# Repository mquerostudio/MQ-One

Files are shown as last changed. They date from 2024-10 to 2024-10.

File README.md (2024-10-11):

# MQ One

Este repositorio contiene todos los archivos creados para mi Trabajo Final de Grado y el **MQ One**: 

***Diseño, validación e implementación de un dispositivo electrónico programable modular***

El proyecto se ha centrado en el **diseño de una nueva plataforma educativa** que facilite el aprendizaje de la **programación de microcontroladores.**

<div align="center">
  
</div>

Para ello he desarrollado el **MQ One**, un dispositivo electrónico programable modular. Incluye **todos los componentes necesarios para enseñar de simple y divertida programación de sistemas embebidos.** Por ello incluye desde los componentes más simples como un encoder y LEDs, hasta más avanzados como una pantalla, una IMU, microSD, micrófono y altavoz.

Toda la información la puedes encontrar en mi web: **[mquero.com](https://mquero.com/)**

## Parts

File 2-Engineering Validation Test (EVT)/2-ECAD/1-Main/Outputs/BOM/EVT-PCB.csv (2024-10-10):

Reference | Value | MQ PN | Part Number | Footprint | Qty
C201,C304,C501,C531,C703,C705,C901,C1001,C1201 | 10u |  |  | Capacitor_SMD:C_0402_1005Metric | 9
C202,C305,C401,C502,C504,C505,C506,C507,C508,C509,C510,C511,C512,C513,C514,C515,C516,C517,C518,C519,C520,C521,C522,C523,C524,C525,C526,C527,C529,C530,C532,C601,C801,C802,C803,C902,C1002,C1103,C1104,C1106,C1108,C1109,C1202,C1205,C1206 | 100n |  |  | Capacitor_SMD:C_0402_1005Metric | 45
C203,C402,C503,C528,C1102,C1105,C1107,C1110,C1203 | 1u |  |  | Capacitor_SMD:C_0402_1005Metric | 9
C302 | 15p |  |  | Capacitor_SMD:C_0402_1005Metric | 1
C303 | 10u | TFGC001 | GRM188R60J106ME47D | Capacitor_SMD:C_0402_1005Metric | 1
C533,C534 | 10n |  |  | Capacitor_SMD:C_0402_1005Metric | 2
C804,C805,C1101 | 22p |  |  | Capacitor_SMD:C_0402_1005Metric | 3
C301,C403,C701 | 22u |  |  | Capacitor_SMD:C_0603_1608Metric | 3
J1302 | Conn_01x09 |  |  | Connector_PinSocket_2.54mm:PinSocket_1x09_P2.54mm_Vertical | 1
J1304 | Conn_01x15 |  |  | Connector_PinSocket_2.54mm:PinSocket_1x15_P2.54mm_Vertical | 1
D1201 | LED |  |  | LED_SMD:LED_0603_1608Metric | 1
R101,R102,R103,R104,R107 | 2k2 |  |  | Resistor_SMD:R_0402_1005Metric | 5
R105,R108,R201,R301,R402,R403,R404,R407,R503,R504,R505,R506,R507,R508,R801,R1101,R1102 | 10k |  |  | Resistor_SMD:R_0402_1005Metric | 17
R109,R110 | 22R |  |  | Resistor_SMD:R_0402_1005Metric | 2
R302,R303 | 5.1k |  |  | Resistor_SMD:R_0402_1005Metric | 2
R304 | 220k |  |  | Resistor_SMD:R_0402_1005Metric | 1
R305 | 48k7 |  |  | Resistor_SMD:R_0402_1005Metric | 1
R306,R601 | 100k |  |  | Resistor_SMD:R_0402_1005Metric | 2
R308,R1201 | 330 |  |  | Resistor_SMD:R_0402_1005Metric | 2
R309 | 1M |  |  | Resistor_SMD:R_0402_1005Metric | 1
R401 | 2k |  |  | Resistor_SMD:R_0402_1005Metric | 1
R405,R501 | 1k |  |  | Resistor_SMD:R_0402_1005Metric | 2
R406 | 150k |  |  | Resistor_SMD:R_0402_1005Metric | 1
R502 | 470 |  |  | Resistor_SMD:R_0402_1005Metric | 1
R901,R902,R903,R904,R905 | 47k |  |  | Resistor_SMD:R_0402_1005Metric | 5
R1001 | 620k |  |  | Resistor_SMD:R_0402_1005Metric | 1
R1103 | 0 |  |  | Resistor_SMD:R_0402_1005Metric | 1
TP101,TP102,TP103,TP104,TP105,TP106,TP107,TP108,TP109,TP110,TP111,TP112,TP113,TP114,TP115,TP116,TP117,TP118,TP119,TP120,TP121,TP122,TP123,TP201,TP202,TP301,TP401,TP501,TP502,TP503,TP504,TP505,TP506,TP507,TP508,TP1001,TP1002,TP1101,TP1102,TP1103,TP1104,TP1108,TP1202,TP1203,TP1204,TP1209,TP1210,TP1301,TP1302,TP1303 | TestPoint |  |  | TestPoint:TestPoint_Pad_D1.0mm | 50
J701 | 2-2328724-1 | TFGJ002 |  | TFG:2-2328724-1 | 1
X801 | 9HT10-32.768KBZF-T | TFGX001 |  | TFG:9HT1032768KEZFT | 1
X1101 | ASE-24.000MHZ-L-R-T | TFGX002 |  | TFG:ASE24576MHZLCT | 1
IC501 | ATSAMD21G18A-MUT | TFGIC015 |  | TFG:ATSAMD21G18A-MUT | 1
D302 | BAT54CWT1G | TFGD005 |  | TFG:BAT54CWT1G | 1
U1202 | BME280 | TFGIC010 |  | TFG:BME280 | 1
U801 | BNO085 | TFGIC004 |  | TFG:BNO085 | 1
Q101 | BSS138-7-F | TFGQ004 |  | TFG:BSS138-7-F | 1
D201,D202,D525,D526,D527,D901,D902,D903,D904,D905,D906 | DESD3V3S1BL-7B | TFGD004 |  | TFG:DESD3V3S1BL-7B | 11
U1104,U1203,U1301 | DS28E07P+ | TFGIC003 |  | TFG:DS28E07P+ | 3
C1204 | DSK-3R3H224U-HL | TFGC002 |  | TFG:DSK-3R3H224U-HL | 1
U201 | ESP32-S3-WROOM-2 | TFGU002 |  | TFG:ESP32-S3-WROOM-2 | 1
U1102 | OV5640 | TFGIC006 |  | TFG:FD5640 | 1
M601 | ICS-43434 | TFGM001 |  | TFG:ICS-43434 | 1
L301 | 1µH | TFGL001 | LQH44PN1R0MPRL | TFG:LQH44PN1R0MPRL | 1
U1001 | MAX98357AETE+T | TFGIC005 |  | TFG:MAX98357AETE+T | 1
U401 | MAX17048G+T10 | TFGIC013 |  | TFG:MAX17048G+T10 | 1
U402 | MCP73833T-FCI/MF | TFGIC001 |  | TFG:MCP73833T | 1
J901 | MSD-1-A | TFGJ003 |  | TFG:MSD1A | 1
U302 | NCV6324BMTAATBG | TFGIC002 |  | TFG:NCV6324BMTAATBG | 1
U301 | NTLJF3117PT1G | TFGQ001 |  | TFG:NTLJF3117PT1G | 1
U1201 | PA1010D | TFGIC009 |  | TFG:PA1010D | 1
E501 | PEC11R-4215F-S0024 | TFGE001 |  | TFG:PEC11R-4215F-S0024 | 1
J401,J1001 | S2B-ZR-SM4A-TF | TFGJ009 |  | TFG:S2B-ZR-SM4A-TF | 2
J101 | SFC-115-T2-F-D-A-K | TFGJ006 |  | TFG:SFC-115-T2-F-D-A | 1
Q301 | SIA527DJ-T1-GE3 | TFGQ003 |  | TFG:SIA527DJ-T1-GE3 | 1
D501,D502,D503,D504,D505,D506,D507,D508,D509,D510,D511,D512,D513,D514,D515,D516,D517,D518,D519,D520,D521,D522,D523,D524 | SK68XX-EC3210F | TFGD001 |  | TFG:SK68XX-EC3210F | 24
J1101,J1201,J1303 | TFC-115-02-F-D-A | TFGJ005 |  | TFG:TFC-115-02-F-D-A | 3
U1103 | TLV74315PDBVR | TFGIC008 |  | TFG:TLV74315PDBVR | 1
U1101 | TLV74328PDBVR | TFGIC007 |  | TFG:TLV74328PDBVR | 1
J301 | USB4105-GF-A | TFGJ004 |  | TFG:USB4105-GF-A | 1
D301 | USBLC6-2SC6 | TFGD006 |  | TFG:USBLC6-2SC6 | 1

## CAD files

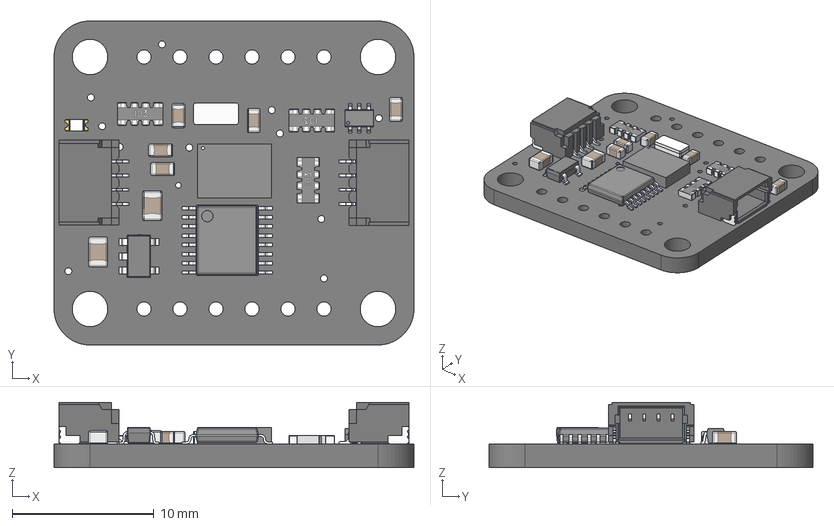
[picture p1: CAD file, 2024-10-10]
1-Proof of Concept (POC)/1-CAD/BNO085.step
25.4 x 22.9 x 4.60 mm
Printed Circuit Board
BNO055-9axis-IMU
BNO085-9axis-IMU
BODY-TSSOP
LEAD-TSSOP x 16
Crystal_XTAL3215_32.768KHz
SOT23-5
BSS138PS
LED 0603 single color
CAPC-0805-T0.95-BN x 2
CAPC-0603-T0.9-BN x 5
YC164_RESPACK x 3
qwicc x 2

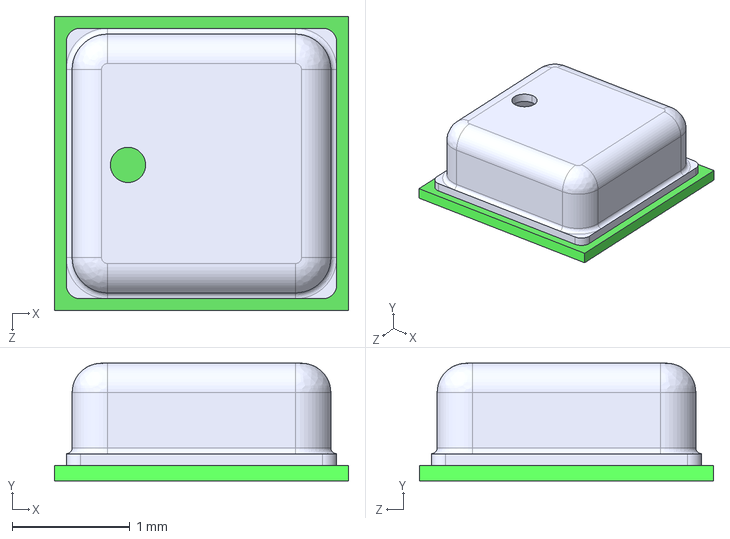
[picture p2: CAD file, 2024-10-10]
3-KiCad_library/3-3D/BME280.stp
2.50 x 1.00 x 2.50 mm

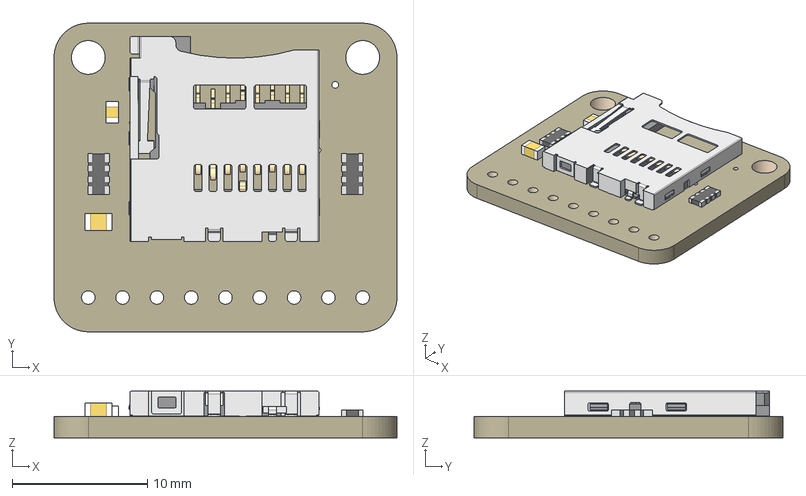
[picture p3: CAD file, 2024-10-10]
1-Proof of Concept (POC)/1-CAD/Micro SD Breakout.step
25.4 x 22.9 x 3.45 mm
Board
microSD
10uF
0.1uF
47K x 2

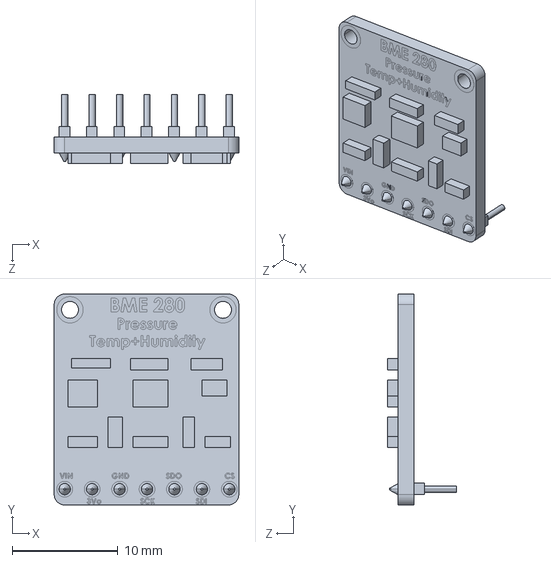
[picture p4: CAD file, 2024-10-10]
1-Proof of Concept (POC)/1-CAD/bme280.STEP
17.5 x 20.0 x 6.51 mm

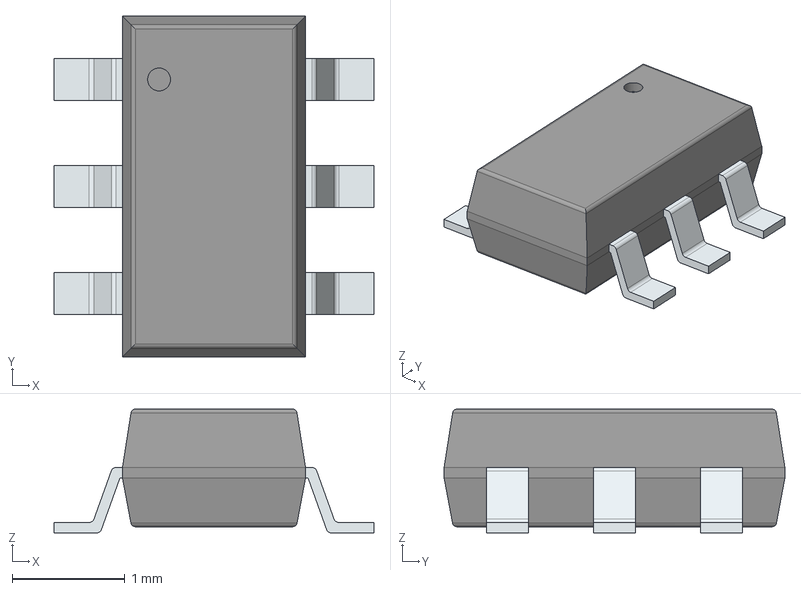
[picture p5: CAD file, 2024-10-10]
3-KiCad_library/3-3D/SI3585CDV-T1-GE3.stp
2.84 x 3.02 x 1.10 mm
PinsArrayLR

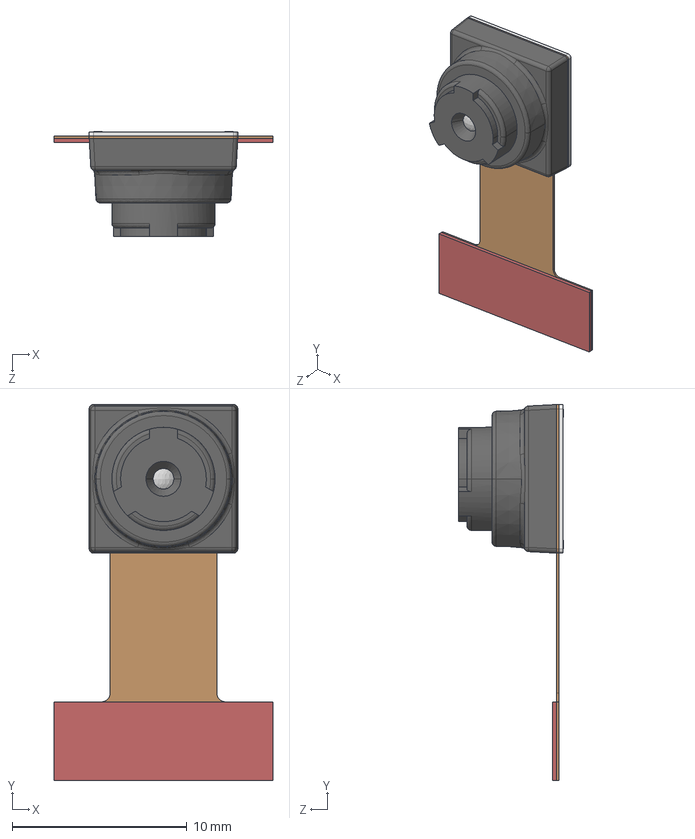
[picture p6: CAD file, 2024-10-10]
3-KiCad_library/3-3D/OV5640.STEP
12.5 x 21.5 x 6.03 mm
ov9655_flex_pcb
ov9655_flex_reinf
ov9655_back_panel
ov9655_body
ov9655_lens

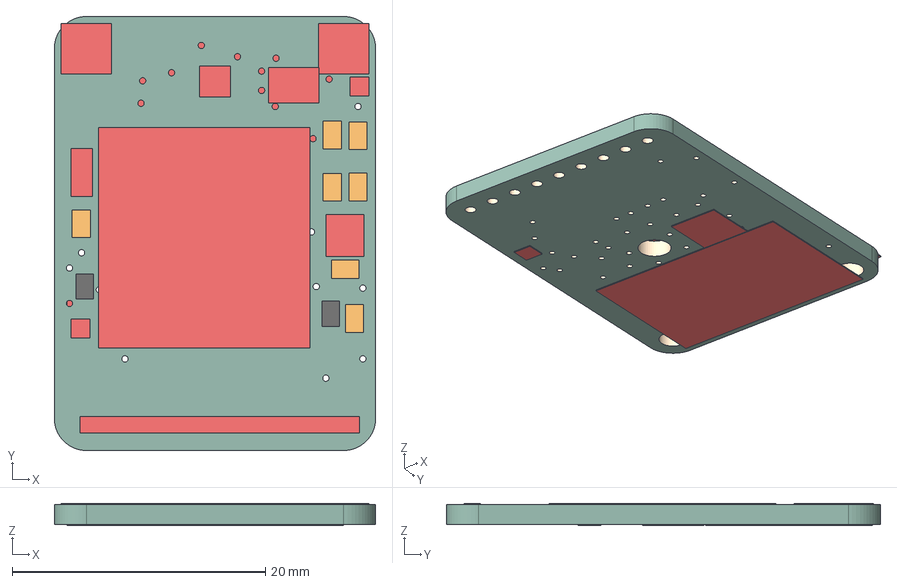
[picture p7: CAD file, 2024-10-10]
1-Proof of Concept (POC)/1-CAD/Adafruit Ultimate GPS.step
25.4 x 34.3 x 1.77 mm
Board
FGPMMOPA6H
MIC5225-3.3
RED
10K x 7
MOUNTINGHOLE2.5 x 2
CUS520 x 2
CR1220
FIDUCIAL"" x 2
ADAFRUIT_2.5MM
U.FL
1X09_ROUND_70
PCBFEAT-REV-040
ADAFRUIT_5MM

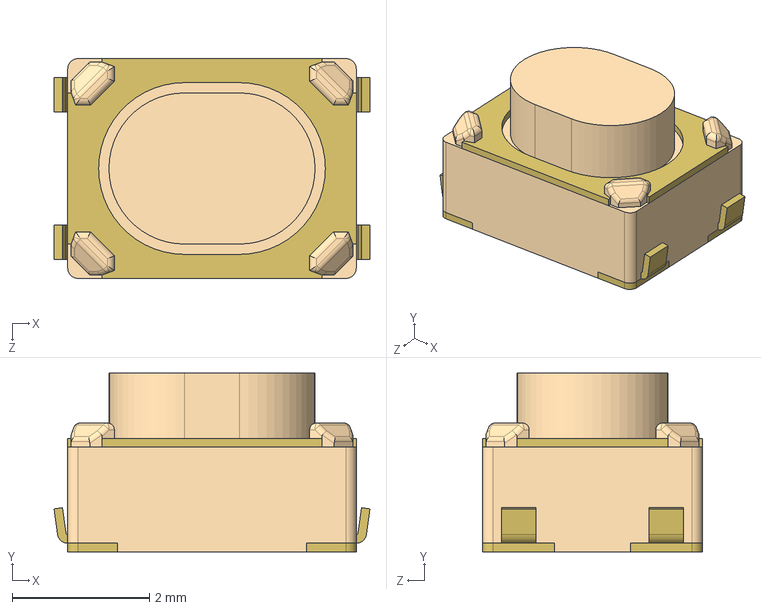
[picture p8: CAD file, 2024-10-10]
3-KiCad_library/3-3D/PTS815.stp
4.60 x 2.60 x 3.20 mm

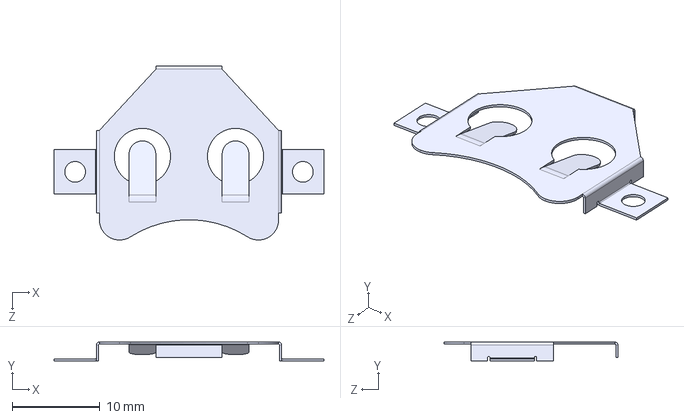
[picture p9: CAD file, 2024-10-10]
3-KiCad_library/3-3D/BK-5067.step
30.7 x 2.16 x 19.8 mm

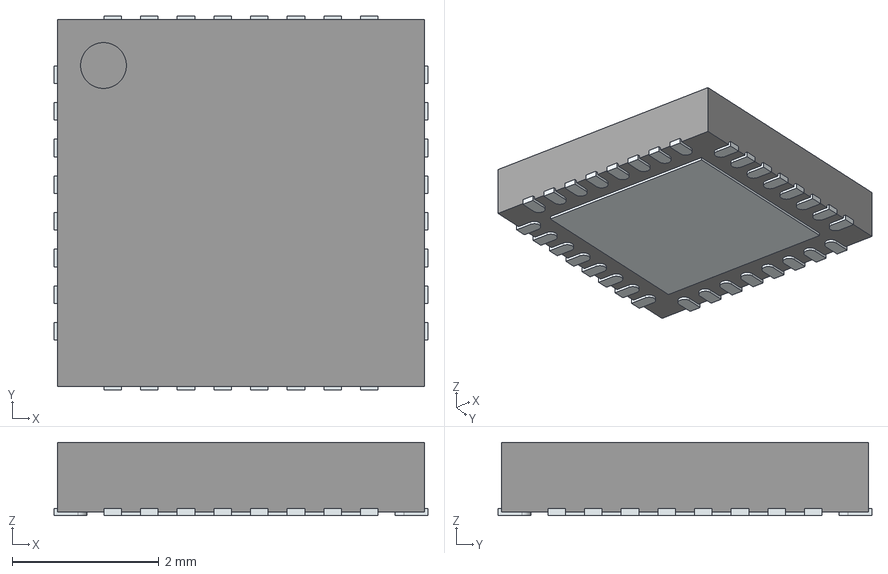
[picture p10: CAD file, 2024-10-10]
3-KiCad_library/3-3D/ATSAMD21E17D-MUT.stp
5.10 x 5.10 x 1.00 mm
ThermalPin
PinsArrayLR
PinsArrayTB

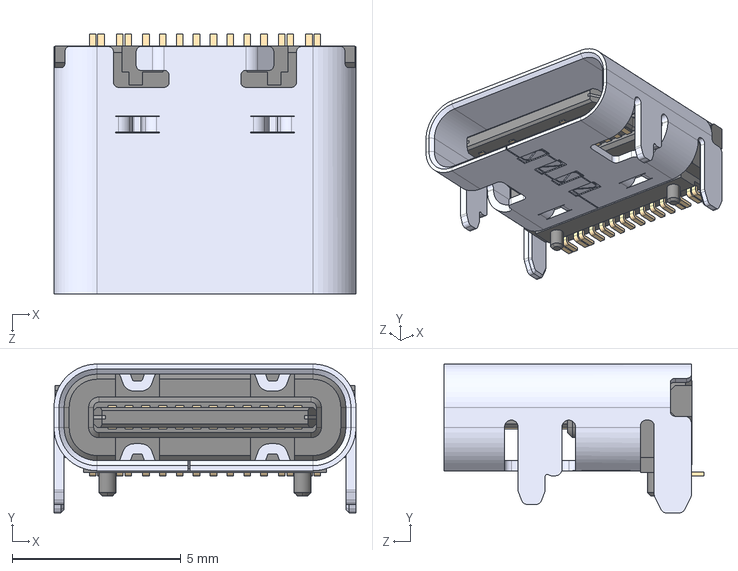
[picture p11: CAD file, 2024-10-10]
3-KiCad_library/3-3D/USB4105-GF-A.step
8.94 x 4.41 x 7.71 mm

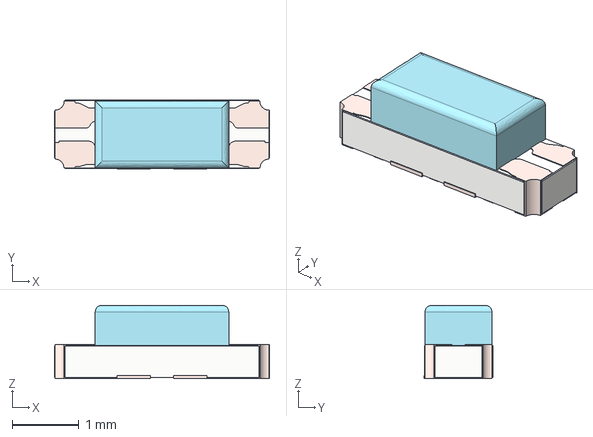
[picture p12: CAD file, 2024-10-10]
3-KiCad_library/3-3D/SK68XX-EC3210F.iges
3.22 x 1.04 x 1.10 mm

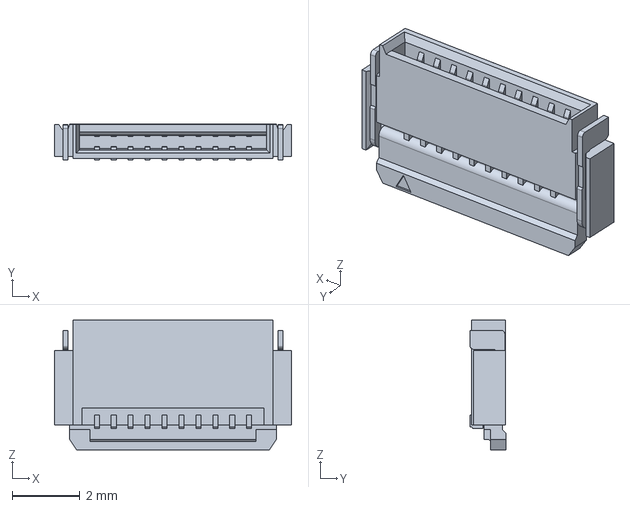
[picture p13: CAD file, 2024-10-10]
3-KiCad_library/3-3D/1-2328702-0.stp
7.00 x 1.06 x 3.83 mm

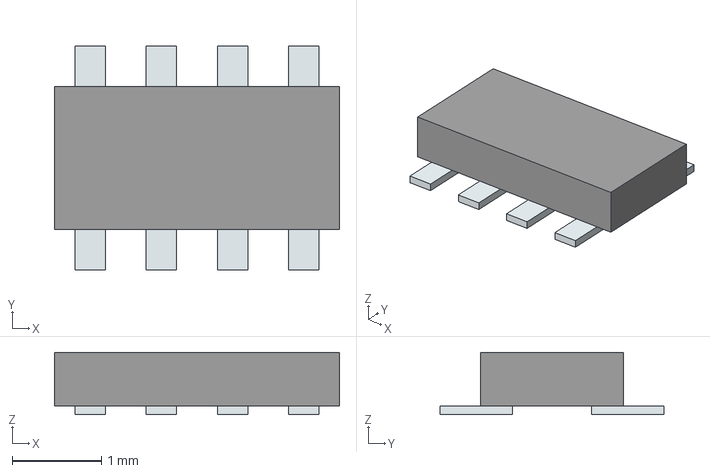
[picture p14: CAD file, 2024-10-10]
3-KiCad_library/3-3D/CAY16-4702F4LF.stp
3.20 x 2.52 x 0.7 mm
Pins

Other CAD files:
3-KiCad_library/3-3D/STPS140A.stp
3-KiCad_library/3-3D/SIA527DJ-T1-GE3.stp
3-KiCad_library/3-3D/USBLC6-2SC6.stp
1-Proof of Concept (POC)/1-CAD/MAX17048.step
1-Proof of Concept (POC)/1-CAD/MAX98357.step
2-Engineering Validation Test (EVT)/1-CAD/CameraModule.f3z
2-Engineering Validation Test (EVT)/1-CAD/EVT-Panel.f3d
2-Engineering Validation Test (EVT)/1-CAD/MakerModule.f3d
2-Engineering Validation Test (EVT)/1-CAD/MountainModule.f3z
3-KiCad_library/3-3D/2-2328724-1.stp
3-KiCad_library/3-3D/5051102491.step
3-KiCad_library/3-3D/9HT10-32.768KBZF-T.step
3-KiCad_library/3-3D/APDS-9960.stp
3-KiCad_library/3-3D/ASE-24.000MHZ-L-R-T.stp
3-KiCad_library/3-3D/ATSAMD09D14A-MUT.stp
3-KiCad_library/3-3D/ATSAMD21G18A-MUT.stp
3-KiCad_library/3-3D/BAT54CWT1G.stp
3-KiCad_library/3-3D/BNO085.stp
3-KiCad_library/3-3D/BSS138-7-F.step
3-KiCad_library/3-3D/DESD3V3S1BL-7B.step
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

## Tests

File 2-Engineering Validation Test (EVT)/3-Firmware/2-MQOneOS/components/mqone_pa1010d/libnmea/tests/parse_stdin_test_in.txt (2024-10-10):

$GPRMC,170058.89,V,3554.928,N,08002.496,W,9.4,1.57,050521,,E*41
$GPGGA,170059.89,3554.928,N,08002.496,W,0,00,,,M,,M,,*6F
$GPGLL,3554.928,N,08002.496,W,170100.89,V*02
$GPGSA,A,3,07,15,08,16,10,09,,,,,,,0.7,0.7,0.5*33
$GPGSV,2,1,06,07,76,278,27,15,07,332,52,08,63,133,57,16,82,309,55*7D
$GPGSV,2,2,06,10,84,275,62,09,30,087,38*78
$GPVTG,360.0,T,348.7,M,000.0,N,000.0,K*43
$GPTXT,01,01,02,u-blox ag - www.u-blox.com*50
$GPGLL,4916.45,N,12311.12,W,225444,A,*1D
$GPGLL,4916.45,N,12311.12,W,225444,A,*D1
$GPGLL,4916.45,N,12311.12,W,225444,A,
$GPGGA,123519,4807.038,N,01131.000,E,1,08,0.9,545.4,M,46.9,M,,*47
$GPGGA,123519,4807.038,N,01131.000,E,1,08,0.9,545.4,M,46.9,M,,*57
$GPGGA,123519,4807.038,N,01131.000,E,1,08,0.9,545.4,M,46.9,M,,
$GPGSA,A,3,04,05,,09,12,,,24,,,,,2.5,1.3,2.1*39
$GPGSV,2,1,08,01,40,083,46,02,17,308,41,12,07,344,39,14,22,228,45*75
$GPRMC,123519,A,4807.038,N,01131.000,E,022.4,084.4,230394,003.1,W*6A
$GPVTG,054.7,T,034.4,M,005.5,N,010.2,K*48
$GPWPL,4807.038,N,01131.000,E,WPTNME*5C
$GPAPB,A,A,0.10,R,N,V,V,011,M,DEST,011,M,011,M*3C

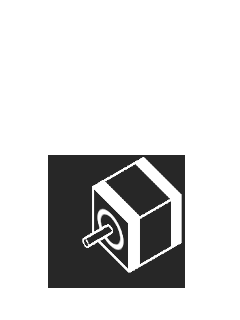
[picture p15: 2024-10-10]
2-Engineering Validation Test (EVT)/3-Firmware/1-TestFW/MQ1_stepper/stepper.png

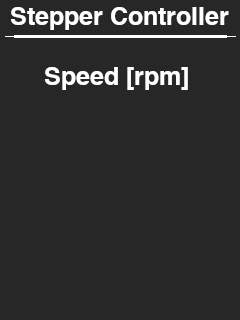
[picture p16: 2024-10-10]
2-Engineering Validation Test (EVT)/3-Firmware/1-TestFW/MQ1_stepper/base.png

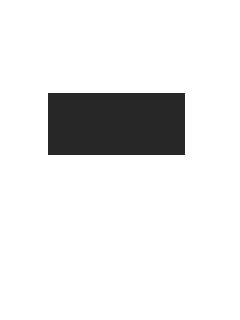
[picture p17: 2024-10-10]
2-Engineering Validation Test (EVT)/3-Firmware/1-TestFW/MQ1_stepper/SpeedBG.png

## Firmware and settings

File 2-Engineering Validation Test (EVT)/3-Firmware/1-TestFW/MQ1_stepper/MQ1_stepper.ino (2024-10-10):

#include "Adafruit_seesaw.h"
#include <seesaw_neopixel.h>

#include <SPI.h>
#include <TFT_eSPI.h>  // Hardware-specific library

#include <AccelStepper.h>

#include <PNGdec.h>
#include "interface.h"  // Image is stored here in an 8-bit array

#define TFT_CS 40
#define TFT_RST 41  // Or set to -1 and connect to Arduino RESET pin
#define TFT_DC 42
#define TFT_MOSI 39  // Data out
#define TFT_SCLK 38  // Clock out

#define NEOPIXEL_PIN 20
#define LED_COUNT 24  // Number of LEDs you have
#define PWR_PIN 7
#define ENCODER_SW_PIN 48

#define MAX_IMAGE_WIDTH 240  // Adjust for your images
#define DELAY_IMAGE 20

#define DIR_PIN 15
#define STEP_PIN 16
#define MOTOR_STEPS 200

Adafruit_seesaw seesaw;
PNG png;                                      // PNG decoder instance
AccelStepper stepper1(1, STEP_PIN, DIR_PIN);  // (Type of driver: with 2 pins, STEP, DIR)
seesaw_NeoPixel strip = seesaw_NeoPixel(24, NEOPIXEL_PIN, NEO_GRB + NEO_KHZ800);
TFT_eSPI tft = TFT_eSPI();  // Invoke custom library

int16_t xpos = 0;
int16_t ypos = 0;

int32_t encoder_position;

TaskHandle_t Task1;
TaskHandle_t Task2;
TaskHandle_t Task3;
TaskHandle_t Task4;

float speed = 0;

void setup() {
  Serial.begin(115200);
  Wire.begin(47, 21);         // SDA on pin 47, SCL on pin 21
  while (!Serial) delay(10);  // wait until serial port is opened

  delay(100);
  Serial.println(F("Seesaw Init"));
  if (!seesaw.begin()) {
    Serial.println(F("seesaw not found!"));
    while (1) delay(10);
  }

  Serial.println(F("Neopixel Init"));
  if (!strip.begin()) {
    Serial.println(F("seesaw pixels not found!"));
    while (1) delay(10);
  }
  Serial.println(F("seesaw started OK!"));

  delay(100);

  seesaw.turnOn();
  pinMode(ENCODER_SW_PIN, INPUT);

  // get starting position
  encoder_position = seesaw.getEncoderPosition();
  seesaw.enableEncoderInterrupt();

  stepper1.setMaxSpeed(1000*32);
  stepper1.setSpeed(0);

  delay(2000);

  xTaskCreatePinnedToCore(Task1code, "Task1", 10000, NULL, 1, &Task1, 0);
  xTaskCreatePinnedToCore(Task2code, "Task2", 10000, NULL, 1, &Task2, 1);
  xTaskCreatePinnedToCore(Task3code, "Task3", 10000, NULL, 1, &Task3, 1);
  xTaskCreatePinnedToCore(Task4code, "Task4", 10000, NULL, 2, &Task4, 1);
}

void Task1code(void *pvParameters) {
  tft.begin();

  float oldspeed = 0;
  int16_t rc;
  int counter = 1;

  rc = png.openFLASH((uint8_t *)base, sizeof(base), pngDraw);
  if (rc == PNG_SUCCESS) {
    tft.startWrite();
    rc = png.decode(NULL, 0);
    tft.endWrite();
    // png.close(); // not needed for memory->memory decode
  }


  for (;;) {
    while (speed != 0) {
      switch (counter) {

        case 1:
          // Print Top Arrow
          rc = png.openFLASH((uint8_t *)stepperArrowTop, sizeof(stepperArrowTop), pngDraw);
          if (rc == PNG_SUCCESS) {
            tft.startWrite();
            rc = png.decode(NULL, 0);
            tft.endWrite();
            tft.endWrite();
            // png.close(); // Required for files, not needed for FLASH arrays
          }
          counter = 2;
          delay(DELAY_IMAGE);
          break;

        case 2:
          // Print Right Arrow
          rc = png.openFLASH((uint8_t *)stepperArrowRight, sizeof(stepperArrowRight), pngDraw);
          if (rc == PNG_SUCCESS) {
            tft.startWrite();
            rc = png.decode(NULL, 0);
            tft.endWrite();
            tft.endWrite();
            // png.close(); // Required for files, not needed for FLASH arrays
          }
          counter = 3;
          delay(DELAY_IMAGE);
          break;

        case 3:
          // Print Bot Arrow
          rc = png.openFLASH((uint8_t *)stepperArrowBot, sizeof(stepperArrowBot), pngDraw);
          if (rc == PNG_SUCCESS) {
            tft.startWrite();
            rc = png.decode(NULL, 0);
            tft.endWrite();
            tft.endWrite();
            // png.close(); // Required for files, not needed for FLASH arrays
          }
          counter = 4;
          delay(DELAY_IMAGE);
          break;

        case 4:
          // Print Left Arrow
          rc = png.openFLASH((uint8_t *)stepperArrowLeft, sizeof(stepperArrowLeft), pngDraw);
          if (rc == PNG_SUCCESS) {
            tft.startWrite();
            rc = png.decode(NULL, 0);
            tft.endWrite();
            tft.endWrite();
            // png.close(); // Required for files, not needed for FLASH arrays
          }
          counter = 1;
          delay(DELAY_IMAGE);
          break;
      }

      if (speed != oldspeed) {
        // Print BG Arrow
        rc = png.openFLASH((uint8_t *)SpeedBG, sizeof(SpeedBG), pngDraw);
        if (rc == PNG_SUCCESS) {
          tft.startWrite();
          rc = png.decode(NULL, 0);
          tft.endWrite();
          tft.endWrite();
          // png.close(); // Required for files, not needed for FLASH arrays
        }
        tft.setCursor(80, 100, 2);
        tft.setTextColor(TFT_WHITE);
        tft.setTextSize(2);
        tft.println(speed);
        oldspeed = speed;

        stepper1.setSpeed(speed*32);
      }
    }

    if (speed == 0) {

      if (speed != oldspeed) {
        // Print BG Arrow
        rc = png.openFLASH((uint8_t *)SpeedBG, sizeof(SpeedBG), pngDraw);
        if (rc == PNG_SUCCESS) {
          tft.startWrite();
          rc = png.decode(NULL, 0);
          tft.endWrite();
          tft.endWrite();
          // png.close(); // Required for files, not needed for FLASH arrays
        }
        tft.setCursor(80, 100, 2);
        tft.setTextColor(TFT_WHITE);
        tft.setTextSize(2);
        tft.println(speed);
        oldspeed = speed;
      }

      rc = png.openFLASH((uint8_t *)stepper, sizeof(stepper), pngDraw);
      if (rc == PNG_SUCCESS) {
        tft.startWrite();
        rc = png.decode(NULL, 0);
        tft.endWrite();
        tft.endWrite();
        // png.close(); // Required for files, not needed for FLASH arrays
      }

      counter = 1;
      delay(10);
    }
  }
}

void Task2code(void *pvParameters) {
  strip.setBrightness(100);
  strip.show();

  for (;;) {
    int32_t new_position = seesaw.getEncoderPosition();

    if (encoder_position != new_position) {
      Serial.println(new_position);  // display new position

      for (int i = 0; i < LED_COUNT; i++) {
        strip.setPixelColor(i, 0);  // Turn off all LEDs
      }

      if (new_position >= 0) {
        int upperBound = min(new_position, static_cast<int32_t>(LED_COUNT - 1));
        for (int i = 0; i <= upperBound; i++) {
          strip.setPixelColor(i, strip.Color(0, 255, 0));  // Green for positive
        }
      } else {
        int startLED = LED_COUNT + new_position;
        for (int i = LED_COUNT - 1; i >= startLED; i--) {
          strip.setPixelColor(i, strip.Color(255, 0, 0));  // Red for negative
        }
      }

      strip.show();
      encoder_position = new_position;  // and save for next round
    }

    speed = encoder_position * 10;
    Serial.println(speed);
    delay(100);
  }
}

void Task3code(void *pvParameters) {
  for (;;) {
    stepper1.runSpeed();
  }
}
void Task4code(void *pvParameters) {
  for (;;) {
    if (!digitalRead(ENCODER_SW_PIN)) {
      seesaw.turnOff();
    }
    delay(500);
  }
}

void loop() {}

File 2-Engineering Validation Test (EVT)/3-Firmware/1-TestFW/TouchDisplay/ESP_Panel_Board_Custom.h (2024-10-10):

/*
 * SPDX-FileCopyrightText: 2023-2024 Espressif Systems (Shanghai) CO LTD
 *
 * SPDX-License-Identifier: Apache-2.0
 */

#pragma once

// *INDENT-OFF*

/* Set to 1 if using a custom board */
#define ESP_PANEL_USE_CUSTOM_BOARD       (1)         // 0/1

#if ESP_PANEL_USE_CUSTOM_BOARD

////////////////////////////////////////////////////////////////////////////////////////////////////////////////////////
//////////////////////////// Please update the following macros to configure the LCD panel /////////////////////////////
////////////////////////////////////////////////////////////////////////////////////////////////////////////////////////
/* Set to 1 when using an LCD panel */
#define ESP_PANEL_USE_LCD           (1)     // 0/1

#if ESP_PANEL_USE_LCD
/**
 * LCD Controller Name. Choose one of the following:
 *      - GC9A01, GC9B71, GC9503
 *      - ILI9341
 *      - NV3022B
 *      - SH8601
 *      - SPD2010
 *      - ST7262, ST7701, ST7789, ST7796, ST77916, ST77922
 */
#define ESP_PANEL_LCD_NAME          ST7789

/* LCD resolution in pixels */
#define ESP_PANEL_LCD_WIDTH         (240)
#define ESP_PANEL_LCD_HEIGHT        (320)

/* LCD Bus Settings */
/**
 * If set to 1, the bus will skip to initialize the corresponding host. Users need to initialize the host in advance.
 * It is useful if other devices use the same host. Please ensure that the host is initialized only once.
 *
 * Set to 1 if only the RGB interface is used without the 3-wire SPI interface,
 */
#define ESP_PANEL_LCD_BUS_SKIP_INIT_HOST    (0)     // 0/1
/**
 * LCD Bus Type. Choose one of the following:
 *      - ESP_PANEL_BUS_TYPE_I2C (not ready)
 *      - ESP_PANEL_BUS_TYPE_SPI
 *      - ESP_PANEL_BUS_TYPE_QSPI
 *      - ESP_PANEL_BUS_TYPE_I80 (not ready)
 *      - ESP_PANEL_BUS_TYPE_RGB (only supported for ESP32-S3)
 */
#define ESP_PANEL_LCD_BUS_TYPE      (ESP_PANEL_BUS_TYPE_SPI)
/**
 * LCD Bus Parameters.
 *
 * Please refer to https://docs.espressif.com/projects/esp-idf/en/latest/esp32s3/api-reference/peripherals/lcd.html and
 * https://docs.espressif.com/projects/esp-iot-solution/en/latest/display/lcd/index.html for more details.
 *
 */
#if ESP_PANEL_LCD_BUS_TYPE == ESP_PANEL_BUS_TYPE_SPI

    #define ESP_PANEL_LCD_BUS_HOST_ID           (1)     // Typically set to 1
    #define ESP_PANEL_LCD_SPI_IO_CS             (40)
#if !ESP_PANEL_LCD_BUS_SKIP_INIT_HOST
    #define ESP_PANEL_LCD_SPI_IO_SCK            (38)
    #define ESP_PANEL_LCD_SPI_IO_MOSI           (39)
    #define ESP_PANEL_LCD_SPI_IO_MISO           (-1)    // -1 if not used
#endif
    #define ESP_PANEL_LCD_SPI_IO_DC             (42)
    #define ESP_PANEL_LCD_SPI_MODE              (0)     // 0/1/2/3, typically set to 0
    #define ESP_PANEL_LCD_SPI_CLK_HZ            (40 * 1000 * 1000)
                                                        // Should be an integer divisor of 80M, typically set to 40M
    #define ESP_PANEL_LCD_SPI_TRANS_QUEUE_SZ    (10)    // Typically set to 10
    #define ESP_PANEL_LCD_SPI_CMD_BITS          (8)     // Typically set to 8
    #define ESP_PANEL_LCD_SPI_PARAM_BITS        (8)     // Typically set to 8

#elif ESP_PANEL_LCD_BUS_TYPE == ESP_PANEL_BUS_TYPE_QSPI

    #define ESP_PANEL_LCD_BUS_HOST_ID           (1)     // Typically set to 1
    #define ESP_PANEL_LCD_SPI_IO_CS             (5)
#if !ESP_PANEL_LCD_BUS_SKIP_INIT_HOST
    #define ESP_PANEL_LCD_SPI_IO_SCK            (9)
    #define ESP_PANEL_LCD_SPI_IO_DATA0          (10)
    #define ESP_PANEL_LCD_SPI_IO_DATA1          (11)
    #define ESP_PANEL_LCD_SPI_IO_DATA2          (12)
    #define ESP_PANEL_LCD_SPI_IO_DATA3          (13)
#endif
    #define ESP_PANEL_LCD_SPI_MODE              (0)     // 0/1/2/3, typically set to 0
    #define ESP_PANEL_LCD_SPI_CLK_HZ            (40 * 1000 * 1000)
                                                        // Should be an integer divisor of 80M, typically set to 40M
    #define ESP_PANEL_LCD_SPI_TRANS_QUEUE_SZ    (10)    // Typically set to 10
    #define ESP_PANEL_LCD_SPI_CMD_BITS          (32)    // Typically set to 32
    #define ESP_PANEL_LCD_SPI_PARAM_BITS        (8)     // Typically set to 8
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
